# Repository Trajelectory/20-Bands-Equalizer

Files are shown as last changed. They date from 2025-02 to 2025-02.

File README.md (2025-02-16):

# Equalizer 20 Bands avec Vumètre LED


## Description du Projet
Ce projet permet de modifier le son en ajustant les niveaux de fréquence tout en affichant visuellement l'intensité du signal audio via un vumètre LED.

## Fonctionnalités
- **Égaliseur graphique 20 bandes** pour un réglage précis des fréquences audio.
- **Vumètre LED** basé sur un circuit spécialisé pour une visualisation dynamique du signal.
- **Entrée et sortie audio** pour intégration dans des systèmes hi-fi ou de studio.
- **Alimentation stabilisée** pour un fonctionnement optimal et sans bruit.
- **Conception optimisée** avec une séparation des pistes minimisant les interférences.

## Matériel Utilisé
- **Logiciel de conception** : KiCad
- **Composants principaux** :
  - Amplificateurs opérationnels (ex: TL074, TL072)
  - Filtres actifs RC pour le traitement du signal
  - Potentiomètres pour le réglage des bandes
  - Circuit de vumètre
  - LED pour l'affichage du signal
  - Connecteurs audio pour l'entrée/sortie

## Fichiers Inclus
- **Schéma KiCad** : `20 Bands Equalizer.kicad_sch`
- **PCB KiCad** : `20 Bands Equalizer.kicad_pcb`
- **Les fichiers de fabrications compatible JLCPCB`

## Améliorations Possibles
- Ajout d'un **affichage LCD** pour afficher les valeurs des bandes.
- Conception d'un **boîtier imprimé en 3D** pour l'intégration.
- Optimisation de l'alimentation pour **baisser la consommation énergétique**.

## Licence
Ce projet est sous licence **MIT**, ce qui signifie que vous pouvez l'utiliser, le modifier et le partager librement en mentionnant l'auteur original.

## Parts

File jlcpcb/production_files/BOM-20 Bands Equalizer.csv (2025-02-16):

Comment | Designator | Footprint | LCSC | Quantity
220nF | C15,C44 | C_0805_2012Metric_Pad1.18x1.45mm_HandSolder | C107131 | 2
33nF | C10,C39 | C_0805_2012Metric_Pad1.18x1.45mm_HandSolder | C107150 | 2
68nF | C36,C7 | C_0805_2012Metric_Pad1.18x1.45mm_HandSolder | C107159 | 2
1M | R11,R20,R52,R61 | R_0805_2012Metric_Pad1.20x1.40mm_HandSolder | C107700 | 4
270pF | C28,C57 | C_0805_2012Metric_Pad1.18x1.45mm_HandSolder | C113858 | 2
390R | R33,R34,R36,R37,R38,R39,R40,R41,R43,R44,R45,R46 | R_0805_2012Metric_Pad1.20x1.40mm_HandSolder | C114543 | 12
220uF | C2 | CP_Elec_10x10 | C125977 | 1
10uF | C32 | C_0805_2012Metric_Pad1.18x1.45mm_HandSolder | C1713 | 1
12nF | C25,C54 | C_0805_2012Metric_Pad1.18x1.45mm_HandSolder | C1715 | 2
150pF | C30,C43,C59,C68 | C_0805_2012Metric_Pad1.18x1.45mm_HandSolder | C1716 | 4
10K | R14,R17,R55,R58 | R_0805_2012Metric_Pad1.20x1.40mm_HandSolder | C17414 | 4
3.9nF | C20,C49 | C_0805_2012Metric_Pad1.18x1.45mm_HandSolder | C1742 | 2
47nF | C21,C50 | C_0805_2012Metric_Pad1.18x1.45mm_HandSolder | C1745 | 2
15K | R10,R51 | R_0805_2012Metric_Pad1.20x1.40mm_HandSolder | C17475 | 2
6.8nF | C27,C56 | C_0805_2012Metric_Pad1.18x1.45mm_HandSolder | C1755 | 2
220K | R13,R16,R21,R23,R25,R27,R29,R31,R47,R50,R54,R57,R6,R62,R64,R66,R68,R70,R72,R9 | R_0805_2012Metric_Pad1.20x1.40mm_HandSolder | C17556 | 20
680K | R3,R4,R5,R74,R75,R76,R77,R78 | R_0805_2012Metric_Pad1.20x1.40mm_HandSolder | C17560 | 8
8.2nF | C16,C45 | C_0805_2012Metric_Pad1.18x1.45mm_HandSolder | C1758 | 2
47K | R49,R8 | R_0805_2012Metric_Pad1.20x1.40mm_HandSolder | C17713 | 2
82K | R35,R42 | R_0805_2012Metric_Pad1.20x1.40mm_HandSolder | C17840 | 2
560pF | C26,C55 | C_0805_2012Metric_Pad1.18x1.45mm_HandSolder | C1829 | 2
390nF | C12,C41 | C_0805_2012Metric_Pad1.18x1.45mm_HandSolder | C1854267 | 2
1uF | C31,C33 | C_0805_2012Metric_Pad1.18x1.45mm_HandSolder | C215803 | 2
2N2222AU | Q1,Q2,Q4 | SOT-89-3_L4.5-W2.4-P1.50-LS4.0-BR | C21714170 | 3
100R | R19,R60 | R_0805_2012Metric_Pad1.20x1.40mm_HandSolder | C25277 | 2
1K | R12,R15,R18,R22,R24,R26,R28,R30,R32,R48,R53,R56,R59,R63,R65,R67,R69,R7,R71,R73 | R_0805_2012Metric_Pad1.20x1.40mm_HandSolder | C25623 | 20
2.2nF | C22,C51 | C_0805_2012Metric_Pad1.18x1.45mm_HandSolder | C28260 | 2
10uF | C4,C5 | C_0805_2012Metric_Pad1.18x1.45mm_HandSolder | C440198 | 2
100nF | C1,C11,C14,C17,C18,C19,C34,C37,C40,C46,C47,C48,C60,C61,C62,C63,C64,C65,C66,C67,C8 | C_0805_2012Metric_Pad1.18x1.45mm_HandSolder | C476766 | 21
LED_RED | D11,D22 | Red-ICE-CUBE-LED-5x5mm-XSCWD23MB-SunLED | C5174712 | 2
LED-GREEN | D12,D4 | Green-ICE-CUBE-LED-5x5mm-XSCWD23MB-SunLED | C5174713 | 2
LED_YELLOW | D19,D8 | Orange-ICE-CUBE-LED-5x5mm-XSCWD23MB-SunLED | C5174714 | 2
18nF | C13,C42 | C_0805_2012Metric_Pad1.18x1.45mm_HandSolder | C5186912 | 2
27nF | C23,C52 | C_0805_2012Metric_Pad1.18x1.45mm_HandSolder | C520042 | 2
2N2907AU | U1 | SOT-89-3_L4.5-W2.5-P1.50-LS4.2-TL | C5362129 | 1
1.5uF | C35,C6 | C_0805_2012Metric_Pad1.18x1.45mm_HandSolder | C6266893 | 2
820nF | C38,C9 | C_0805_2012Metric_Pad1.18x1.45mm_HandSolder | C67958 | 2
TL082 | U11 | SOIC-8_3.9x4.9mm_P1.27mm | C6966 | 1
NE5532 | U8,U9 | SOIC-8_3.9x4.9mm_P1.27mm | C7426 | 2
3.3nF | C29,C58 | C_0805_2012Metric_Pad1.18x1.45mm_HandSolder | C7467177 | 2
1N4148 | D13,D14,D16,D18,D2,D20,D3,D5,D7,D9 | D_SOD-123 | C83528 | 10
1nF | C24,C53 | C_0805_2012Metric_Pad1.18x1.45mm_HandSolder | C94121 | 2
5K |  | Potentiometer_Bourns_PTA3043_Single_Slide |  | 0
10K |  | Potentiometer_Bourns_PTA3043_Single_Slide |  | 0
LM324 |  | DIP-14_W7.62mm_LongPads |  | 0
250K |  | Potentiometer_Bourns_PTA2043_Single_Slide |  | 0
AUDIO OUT |  | Jack_3.5mm_CUI_SJ1-3523N_Horizontal |  | 0
LM324 |  | DIP-14_W7.62mm_LongPads |  | 0
5K |  | Potentiometer_Bourns_PTA3043_Single_Slide |  | 0
250K |  | Potentiometer_Bourns_PTA2043_Single_Slide |  | 0
5K |  | Potentiometer_Bourns_PTA3043_Single_Slide |  | 0
LM324 |  | DIP-14_W7.62mm_LongPads |  | 0
SPEAKER_R |  | JST_XH_S2B-XH-A-1_1x02_P2.50mm_Horizontal |  | 0
5K |  | Potentiometer_Bourns_PTA3043_Single_Slide |  | 0
10K |  | Potentiometer_Bourns_PTA3043_Single_Slide |  | 0
10K |  | Potentiometer_Bourns_PTA3043_Single_Slide |  | 0
10K |  | Potentiometer_Bourns_PTA3043_Single_Slide |  | 0
5K |  | Potentiometer_Bourns_PTA3043_Single_Slide |  | 0
5K |  | Potentiometer_Bourns_PTA3043_Single_Slide |  | 0
10K |  | Potentiometer_Bourns_PTA3043_Single_Slide |  | 0
10K |  | Potentiometer_Bourns_PTA3043_Single_Slide |  | 0
LM324 |  | DIP-14_W7.62mm_LongPads |  | 0
10K |  | Potentiometer_Bourns_PTA3043_Single_Slide |  | 0
5K |  | Potentiometer_Bourns_PTA3043_Single_Slide |  | 0
SPEAKER_L |  | JST_XH_S2B-XH-A-1_1x02_P2.50mm_Horizontal |  | 0
LM324 |  | DIP-14_W7.62mm_LongPads |  | 0
DC Jack VIN 30VDC |  | BarrelJack_GCT_DCJ200-10-A_Horizontal |  | 0
AUDIO IN |  | Jack_3.5mm_CUI_SJ1-3523N_Horizontal |  | 0
LM324 |  | DIP-14_W7.62mm_LongPads |  | 0
10K |  | Potentiometer_Bourns_PTA3043_Single_Slide |  | 0
10K |  | Potentiometer_Bourns_PTA3043_Single_Slide |  | 0
5K |  | Potentiometer_Bourns_PTA3043_Single_Slide |  | 0
10K |  | Potentiometer_Bourns_PTA3043_Single_Slide |  | 0
5K |  | Potentiometer_Bourns_PTA3043_Single_Slide |  | 0
5K |  | Potentiometer_Bourns_PTA3043_Single_Slide |  | 0

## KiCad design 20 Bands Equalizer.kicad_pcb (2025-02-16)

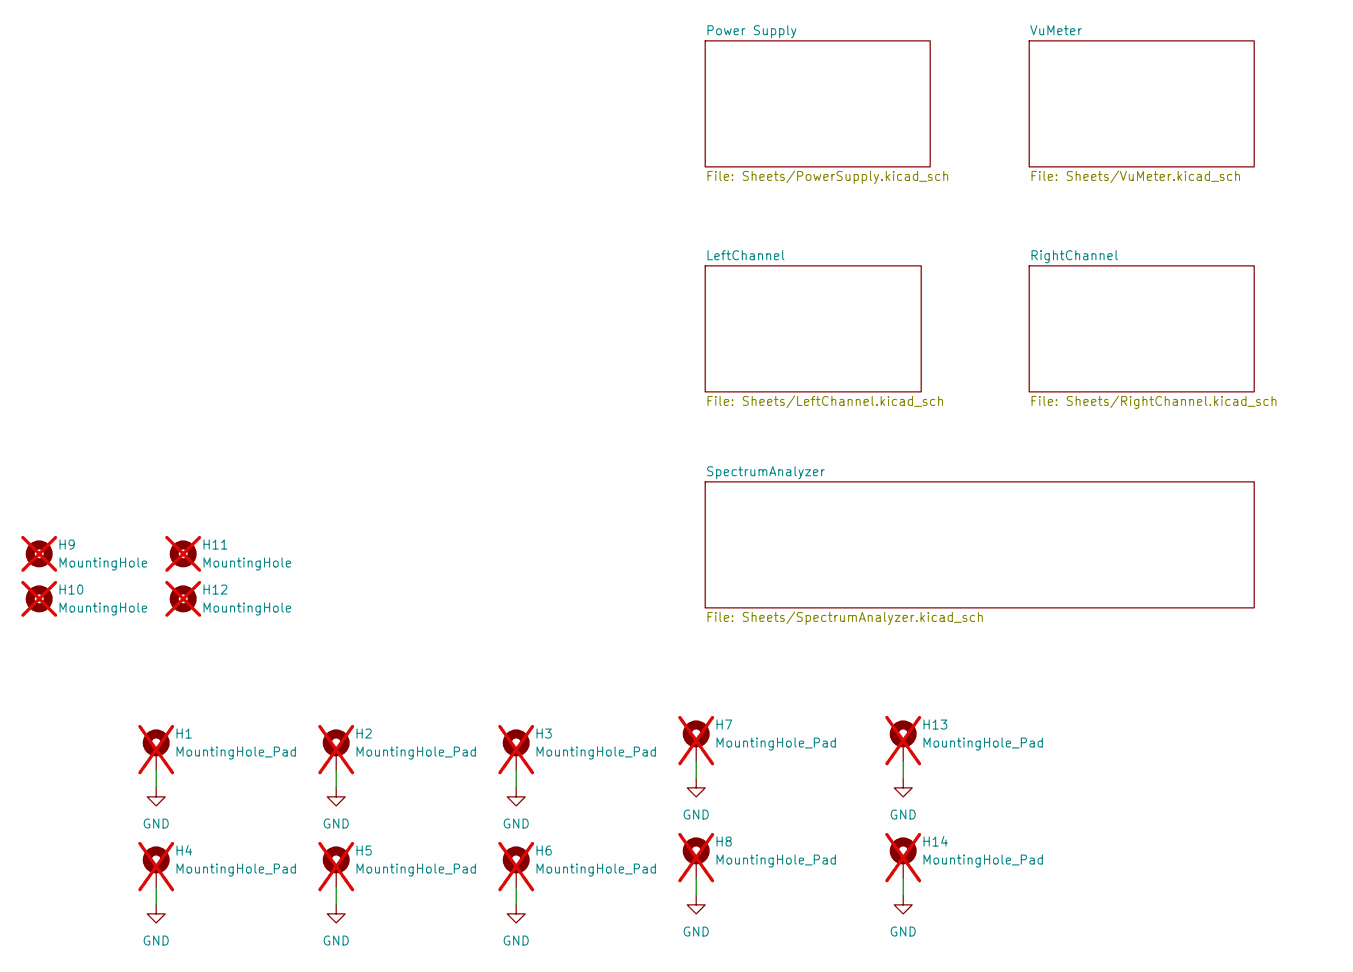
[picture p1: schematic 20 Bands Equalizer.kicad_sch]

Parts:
H1, H2, H3, H4, H5, H6, H7, H8, H13, H14: MountingHole_Pad; MountingHole_3.2mm_M3_Pad_Via; not fitted
H9, H10, H11, H12: MountingHole; MountingHole_2.5mm; not fitted

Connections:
0V: H1.1, H2.1, H3.1, H4.1, H5.1, H6.1, H7.1, H8.1, H13.1, H14.1; also elsewhere on the board

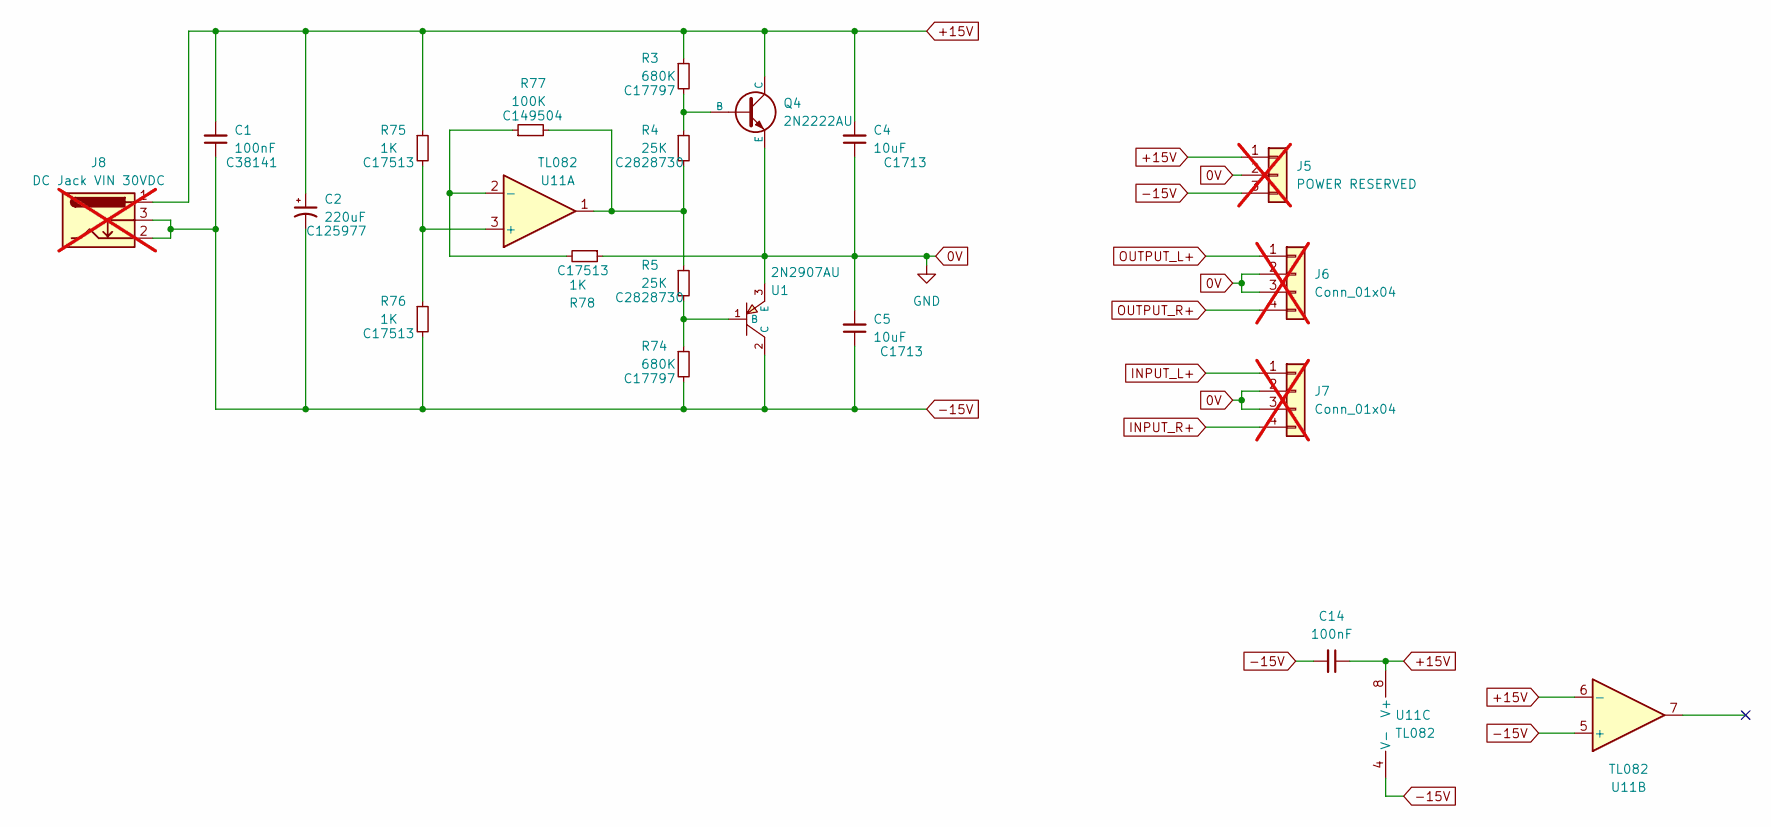
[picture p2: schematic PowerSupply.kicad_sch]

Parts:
C1, C14: 100nF; C_0805_2012Metric_Pad1.18x1.45mm_HandSolder; LCSC C38141
C2: 220uF; CP_Elec_10x10; LCSC C125977
C4, C5: 10uF; C_0805_2012Metric_Pad1.18x1.45mm_HandSolder; LCSC C1713
J5: POWER RESERVED; JST_XH_B3B-XH-A_1x03_P2.50mm_Vertical; not fitted
J6, J7: Conn_01x04; JST_XH_B4B-XH-A_1x04_P2.50mm_Vertical; not fitted
J8: DC Jack VIN 30VDC; BarrelJack_GCT_DCJ200-10-A_Horizontal; not fitted
Q4: 2N2222AU; SOT-89-3_L4.5-W2.4-P1.50-LS4.0-BR; LCSC C21714170
R3, R74: 680K; R_0805_2012Metric_Pad1.20x1.40mm_HandSolder; LCSC C17797
R4, R5: 25K; R_0805_2012Metric_Pad1.20x1.40mm_HandSolder; LCSC C2828730
R75, R76, R78: 1K; R_0805_2012Metric_Pad1.20x1.40mm_HandSolder; LCSC C17513
R77: 100K; R_0805_2012Metric_Pad1.20x1.40mm_HandSolder; LCSC C149504
U1: 2N2907AU; SOT-89-3_L4.5-W2.5-P1.50-LS4.2-TL; LCSC C5362129
U11: TL082; SOIC-8_3.9x4.9mm_P1.27mm; LCSC C6966

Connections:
0V: C4.1, C5.2, J5.2, J6.2, J6.3, J7.2, J7.3, Q4.3 (E), R78.1, U1.3 (E); also elsewhere on the board
+15V: C1.2, C2.1, C4.2, C14.1, J5.1, J8.1, Q4.2 (C), R3.1, R75.1, U11.6 (-), U11.8 (V+); also elsewhere on the board
-15V: C1.1, C2.2, C5.1, C14.2, J5.3, J8.2, J8.3, R74.2, R76.2, U1.2 (C), U11.4 (V-), U11.5 (+); also elsewhere on the board
INPUT_L+: J7.1; also elsewhere on the board
INPUT_R+: J7.4; also elsewhere on the board
unnamed: Q4.1 (B), R3.2, R4.1
unnamed: R4.2, R5.1, R77.2, U11.1
unnamed: R5.2, R74.1, U1.1 (B)
unnamed: R75.2, R76.1, U11.3 (+)
unnamed: R77.1, R78.2, U11.2 (-)
OUTPUT_L+: J6.1; also elsewhere on the board
OUTPUT_R+: J6.4; also elsewhere on the board

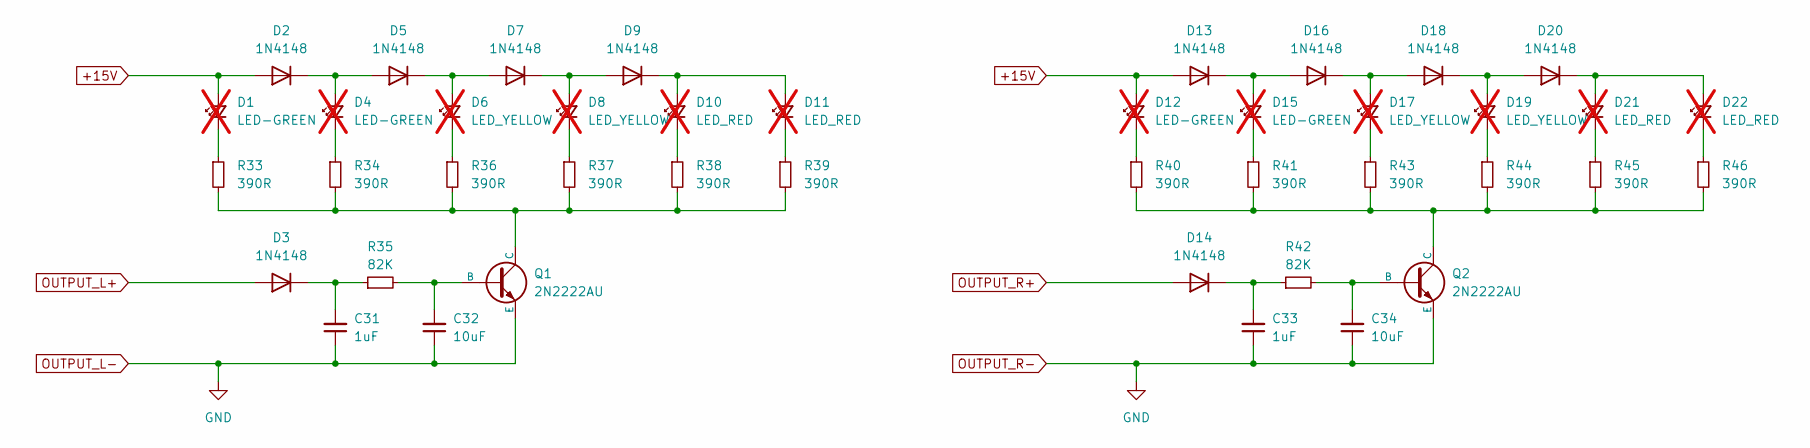
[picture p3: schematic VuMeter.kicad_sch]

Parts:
C31, C33: 1uF; C_0805_2012Metric_Pad1.18x1.45mm_HandSolder; LCSC C28323
C32, C34: 10uF; C_0805_2012Metric_Pad1.18x1.45mm_HandSolder; LCSC C1713
D1, D4, D12, D15: LED-GREEN; Green-ICE-CUBE-LED-5x5mm-XSCWD23MB-SunLED; LCSC C5174713; not fitted
D2, D3, D5, D7, D9, D13, D14, D16, D18, D20: 1N4148; D_SOD-123; LCSC C83528
D6, D8, D17, D19: LED_YELLOW; Orange-ICE-CUBE-LED-5x5mm-XSCWD23MB-SunLED; LCSC C5174714; not fitted
D10, D11, D21, D22: LED_RED; Red-ICE-CUBE-LED-5x5mm-XSCWD23MB-SunLED; LCSC C5174712; not fitted
Q1, Q2: 2N2222AU; SOT-89-3_L4.5-W2.4-P1.50-LS4.0-BR; LCSC C21714170
R33, R34, R36, R37, R38, R39, R40, R41, R43, R44, R45, R46: 390R; R_0805_2012Metric_Pad1.20x1.40mm_HandSolder; LCSC C17655
R35, R42: 82K; R_0805_2012Metric_Pad1.20x1.40mm_HandSolder; LCSC C17840

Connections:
0V: C31.1, C32.1, C33.1, C34.1, Q1.3 (E), Q2.3 (E); also elsewhere on the board
+15V: D1.2 (A), D2.2 (A), D12.2 (A), D13.2 (A); also elsewhere on the board
unnamed: D1.1 (K), R33.1
unnamed: D2.1 (K), D4.2 (A), D5.2 (A)
unnamed: C31.2, D3.1 (K), R35.1
unnamed: D4.1 (K), R34.1
unnamed: D5.1 (K), D6.2 (A), D7.2 (A)
unnamed: D6.1 (K), R36.1
unnamed: D7.1 (K), D8.2 (A), D9.2 (A)
unnamed: D8.1 (K), R37.1
unnamed: D9.1 (K), D10.2 (A), D11.2 (A)
unnamed: D10.1 (K), R38.1
unnamed: D11.1 (K), R39.1
unnamed: D12.1 (K), R40.1
unnamed: D13.1 (K), D15.2 (A), D16.2 (A)
unnamed: C33.2, D14.1 (K), R42.1
unnamed: D15.1 (K), R41.1
unnamed: D16.1 (K), D17.2 (A), D18.2 (A)
unnamed: D17.1 (K), R43.1
unnamed: D18.1 (K), D19.2 (A), D20.2 (A)
unnamed: D19.1 (K), R44.1
unnamed: D20.1 (K), D21.2 (A), D22.2 (A)
unnamed: D21.1 (K), R45.1
unnamed: D22.1 (K), R46.1
unnamed: C32.2, Q1.1 (B), R35.2
unnamed: Q1.2 (C), R33.2, R34.2, R36.2, R37.2, R38.2, R39.2
unnamed: C34.2, Q2.1 (B), R42.2
unnamed: Q2.2 (C), R40.2, R41.2, R43.2, R44.2, R45.2, R46.2
OUTPUT_L+: D3.2 (A); also elsewhere on the board
OUTPUT_R+: D14.2 (A); also elsewhere on the board

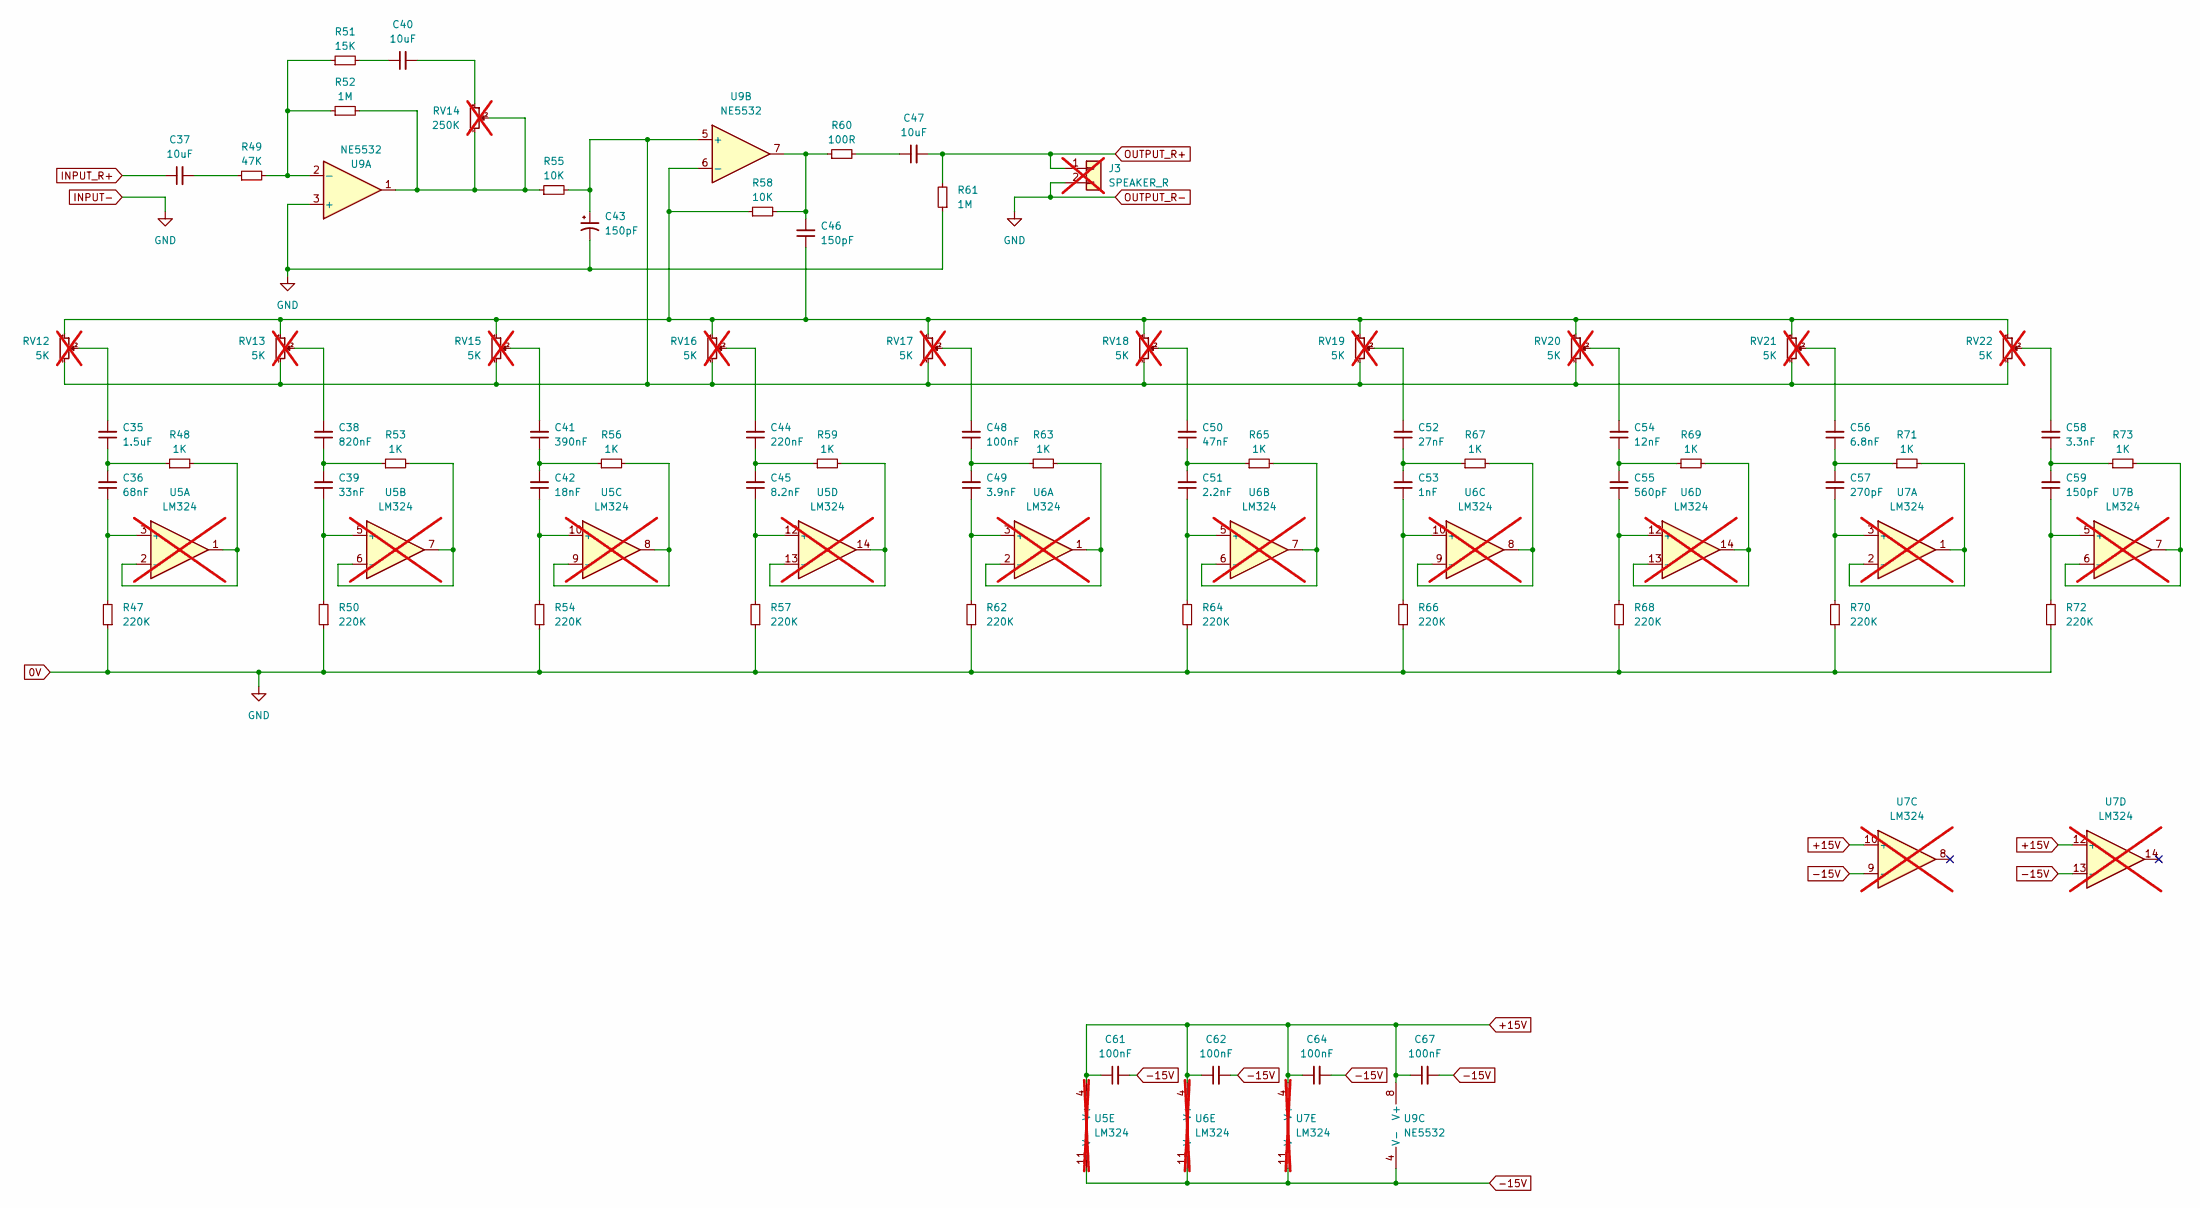
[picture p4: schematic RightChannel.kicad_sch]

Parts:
C35: 1.5uF; C_0805_2012Metric_Pad1.18x1.45mm_HandSolder; LCSC C6266893
C36: 68nF; C_0805_2012Metric_Pad1.18x1.45mm_HandSolder; LCSC C107159
C37, C40, C47: 10uF; C_0805_2012Metric_Pad1.18x1.45mm_HandSolder; LCSC C1713
C38: 820nF; C_0805_2012Metric_Pad1.18x1.45mm_HandSolder; LCSC C67958
C39: 33nF; C_0805_2012Metric_Pad1.18x1.45mm_HandSolder; LCSC C344201
C41: 390nF; C_0805_2012Metric_Pad1.18x1.45mm_HandSolder; LCSC C841545
C42: 18nF; C_0805_2012Metric_Pad1.18x1.45mm_HandSolder; LCSC C5186912
C43, C46, C59: 150pF; C_0805_2012Metric_Pad1.18x1.45mm_HandSolder; LCSC C107111
C44: 220nF; C_0805_2012Metric_Pad1.18x1.45mm_HandSolder; LCSC C6119934
C45: 8.2nF; C_0805_2012Metric_Pad1.18x1.45mm_HandSolder; LCSC C5186918
C48, C61, C62, C64, C67: 100nF; C_0805_2012Metric_Pad1.18x1.45mm_HandSolder; LCSC C38141
C49: 3.9nF; C_0805_2012Metric_Pad1.18x1.45mm_HandSolder; LCSC C97901
C50: 47nF; C_0805_2012Metric_Pad1.18x1.45mm_HandSolder; LCSC C107154
C51: 2.2nF; C_0805_2012Metric_Pad1.18x1.45mm_HandSolder; LCSC C36576
C52: 27nF; C_0805_2012Metric_Pad1.18x1.45mm_HandSolder; LCSC C520042
C53: 1nF; C_0805_2012Metric_Pad1.18x1.45mm_HandSolder; LCSC C94121
C54: 12nF; C_0805_2012Metric_Pad1.18x1.45mm_HandSolder; LCSC C38141
C55: 560pF; C_0805_2012Metric_Pad1.18x1.45mm_HandSolder; LCSC C107119
C56: 6.8nF; C_0805_2012Metric_Pad1.18x1.45mm_HandSolder; LCSC C1755
C57: 270pF; C_0805_2012Metric_Pad1.18x1.45mm_HandSolder; LCSC C113828
C58: 3.3nF; C_0805_2012Metric_Pad1.18x1.45mm_HandSolder; LCSC C7467177
J3: SPEAKER_R; JST_XH_S2B-XH-A-1_1x02_P2.50mm_Horizontal; not fitted
R47, R50, R54, R57, R62, R64, R66, R68, R70, R72: 220K; R_0805_2012Metric_Pad1.20x1.40mm_HandSolder; LCSC C17556
R48, R53, R56, R59, R63, R65, R67, R69, R71, R73: 1K; R_0805_2012Metric_Pad1.20x1.40mm_HandSolder; LCSC C17513
R49: 47K; R_0805_2012Metric_Pad1.20x1.40mm_HandSolder; LCSC C102018
R51: 15K; R_0805_2012Metric_Pad1.20x1.40mm_HandSolder; LCSC C17475
R52, R61: 1M; R_0805_2012Metric_Pad1.20x1.40mm_HandSolder; LCSC C17514
R55, R58: 10K; R_0805_2012Metric_Pad1.20x1.40mm_HandSolder; LCSC C17414
R60: 100R; R_0805_2012Metric_Pad1.20x1.40mm_HandSolder; LCSC C17408
RV12, RV13, RV15, RV16, RV17, RV18, RV19, RV20, RV21, RV22: 5K; Potentiometer_Bourns_PTA3043_Single_Slide; LCSC 652-PTA30432015CPB50; not fitted
RV14: 250K; Potentiometer_Bourns_PTA2043_Single_Slide; LCSC 652-PTA2432010CIB254; not fitted
U5, U6, U7: LM324; DIP-14_W7.62mm_LongPads; not fitted
U9: NE5532; SOIC-8_3.9x4.9mm_P1.27mm; LCSC C7426

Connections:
0V: C43.2, J3.2, R47.1, R50.1, R54.1, R57.1, R61.1, R62.1, R64.1, R66.1, R68.1, R70.1, R72.1, U9.3 (+); also elsewhere on the board
+15V: C61.1, C62.1, C64.1, C67.1, U5.4 (V+), U6.4 (V+), U7.4 (V+), U7.10 (+), U7.12 (+), U9.8 (V+); also elsewhere on the board
-15V: C61.2, C62.2, C64.2, C67.2, U5.11 (V-), U6.11 (V-), U7.9 (-), U7.11 (V-), U7.13 (-), U9.4 (V-); also elsewhere on the board
INPUT_R+: C37.1; also elsewhere on the board
unnamed: C35.1, C36.2, R48.1
unnamed: C35.2, RV12.2
unnamed: C37.2, R49.1
unnamed: C38.1, C39.2, R53.1
unnamed: C38.2, RV13.2
unnamed: C40.1, R51.2
unnamed: C40.2, RV14.1
unnamed: C41.1, C42.2, R56.1
unnamed: C41.2, RV15.2
unnamed: C44.1, C45.2, R59.1
unnamed: C44.2, RV16.2
unnamed: C46.2, R58.2, R60.1, U9.7
unnamed: C47.1, R60.2
unnamed: C48.1, C49.2, R63.1
unnamed: C48.2, RV17.2
unnamed: C50.1, C51.2, R65.1
unnamed: C50.2, RV18.2
unnamed: C52.1, C53.2, R67.1
unnamed: C52.2, RV19.2
unnamed: C54.1, C55.2, R69.1
unnamed: C54.2, RV20.2
unnamed: C56.1, C57.2, R71.1
unnamed: C56.2, RV21.2
unnamed: C58.1, C59.2, R73.1
unnamed: C58.2, RV22.2
unnamed: R52.2, R55.1, RV14.2, RV14.3, U9.1
unnamed: C36.1, R47.2, U5.3 (+)
unnamed: R48.2, U5.1, U5.2 (-)
unnamed: C39.1, R50.2, U5.5 (+)
unnamed: R53.2, U5.6 (-), U5.7
unnamed: C42.1, R54.2, U5.10 (+)
unnamed: R56.2, U5.8, U5.9 (-)
unnamed: C45.1, R57.2, U5.12 (+)
unnamed: R59.2, U5.13 (-), U5.14
unnamed: C49.1, R62.2, U6.3 (+)
unnamed: R63.2, U6.1, U6.2 (-)
unnamed: C51.1, R64.2, U6.5 (+)
unnamed: R65.2, U6.6 (-), U6.7
unnamed: C53.1, R66.2, U6.10 (+)
unnamed: R67.2, U6.8, U6.9 (-)
unnamed: C55.1, R68.2, U6.12 (+)
unnamed: R69.2, U6.13 (-), U6.14
unnamed: C57.1, R70.2, U7.3 (+)
unnamed: R71.2, U7.1, U7.2 (-)
unnamed: C59.1, R72.2, U7.5 (+)
unnamed: R73.2, U7.6 (-), U7.7
unnamed: R49.2, R51.1, R52.1, U9.2 (-)
unnamed: C43.1, R55.2, RV12.3, RV13.3, RV15.3, RV16.3, RV17.3, RV18.3, RV19.3, RV20.3, RV21.3, RV22.3, U9.5 (+)
unnamed: C46.1, R58.1, RV12.1, RV13.1, RV15.1, RV16.1, RV17.1, RV18.1, RV19.1, RV20.1, RV21.1, RV22.1, U9.6 (-)
OUTPUT_R+: C47.2, J3.1, R61.2; also elsewhere on the board

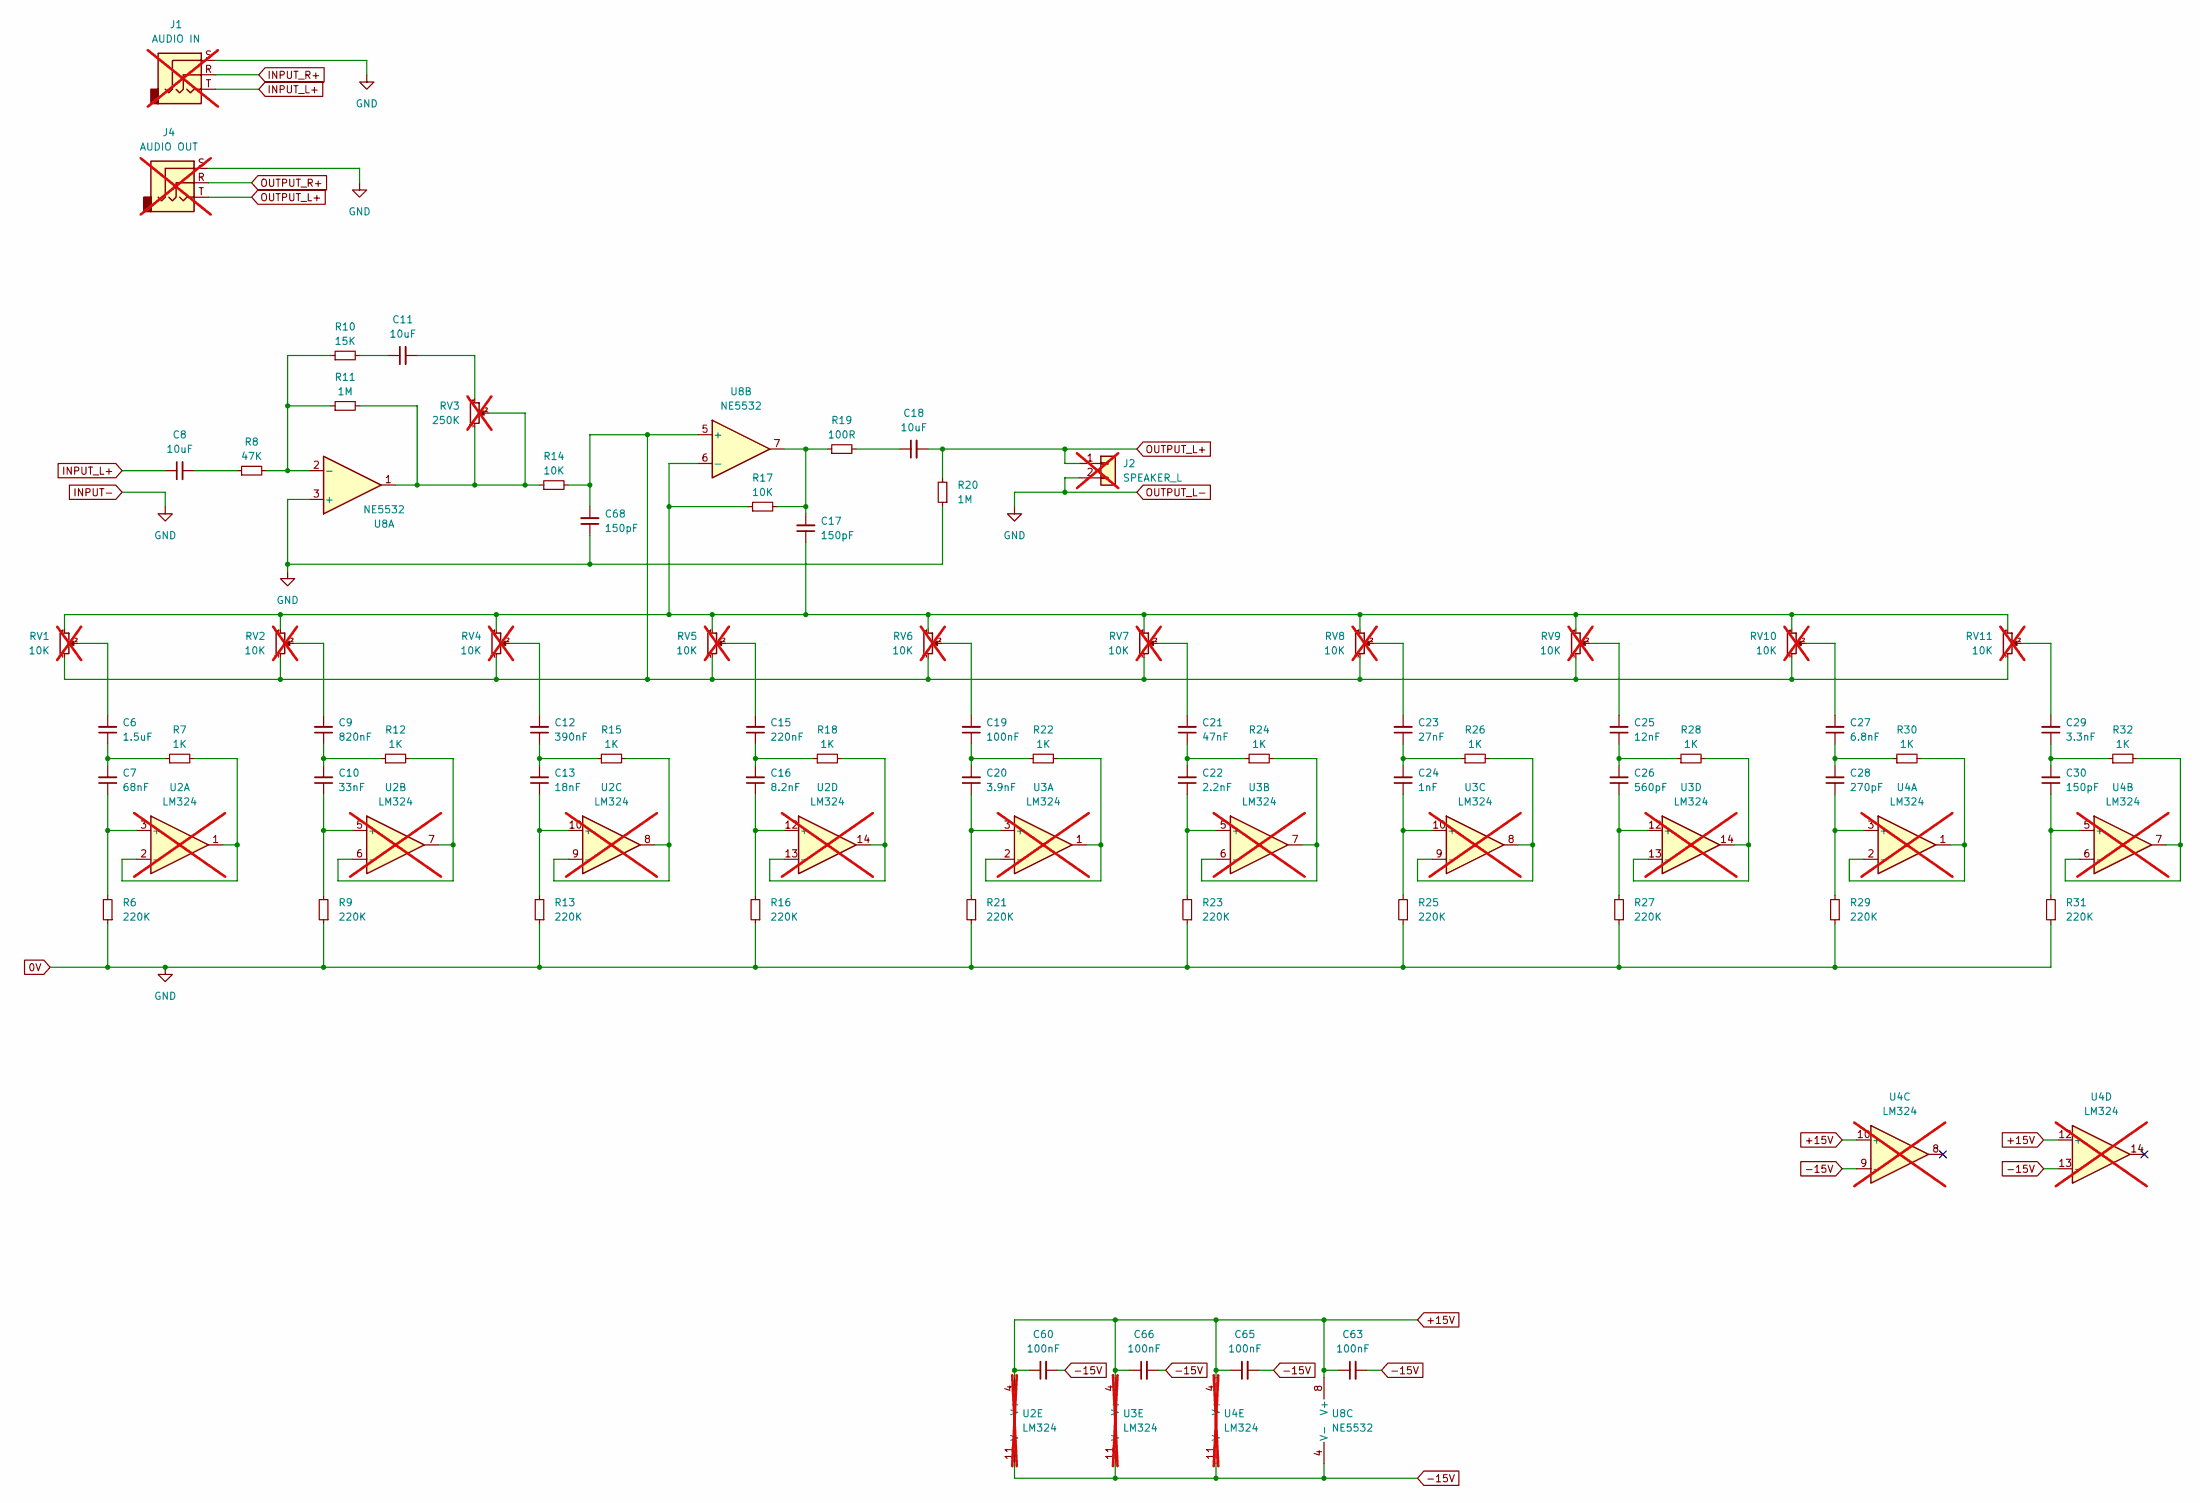
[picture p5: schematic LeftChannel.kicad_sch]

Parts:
C6: 1.5uF; C_0805_2012Metric_Pad1.18x1.45mm_HandSolder; LCSC C6266893
C7: 68nF; C_0805_2012Metric_Pad1.18x1.45mm_HandSolder; LCSC C107159
C8, C11, C18: 10uF; C_0805_2012Metric_Pad1.18x1.45mm_HandSolder; LCSC C1713
C9: 820nF; C_0805_2012Metric_Pad1.18x1.45mm_HandSolder; LCSC C67958
C10: 33nF; C_0805_2012Metric_Pad1.18x1.45mm_HandSolder; LCSC C344201
C12: 390nF; C_0805_2012Metric_Pad1.18x1.45mm_HandSolder; LCSC C841545
C13: 18nF; C_0805_2012Metric_Pad1.18x1.45mm_HandSolder; LCSC C5186912
C15: 220nF; C_0805_2012Metric_Pad1.18x1.45mm_HandSolder; LCSC C6119934
C16: 8.2nF; C_0805_2012Metric_Pad1.18x1.45mm_HandSolder; LCSC C5186918
C17, C30, C68: 150pF; C_0805_2012Metric_Pad1.18x1.45mm_HandSolder; LCSC C107111
C19, C60, C63, C65, C66: 100nF; C_0805_2012Metric_Pad1.18x1.45mm_HandSolder; LCSC C38141
C20: 3.9nF; C_0805_2012Metric_Pad1.18x1.45mm_HandSolder; LCSC C97901
C21: 47nF; C_0805_2012Metric_Pad1.18x1.45mm_HandSolder; LCSC C107154
C22: 2.2nF; C_0805_2012Metric_Pad1.18x1.45mm_HandSolder; LCSC C36576
C23: 27nF; C_0805_2012Metric_Pad1.18x1.45mm_HandSolder; LCSC C520042
C24: 1nF; C_0805_2012Metric_Pad1.18x1.45mm_HandSolder; LCSC C94121
C25: 12nF; C_0805_2012Metric_Pad1.18x1.45mm_HandSolder; LCSC C38141
C26: 560pF; C_0805_2012Metric_Pad1.18x1.45mm_HandSolder; LCSC C107119
C27: 6.8nF; C_0805_2012Metric_Pad1.18x1.45mm_HandSolder; LCSC C1755
C28: 270pF; C_0805_2012Metric_Pad1.18x1.45mm_HandSolder; LCSC C113828
C29: 3.3nF; C_0805_2012Metric_Pad1.18x1.45mm_HandSolder; LCSC C7467177
J1: AUDIO IN; Jack_3.5mm_CUI_SJ1-3523N_Horizontal; not fitted
J2: SPEAKER_L; JST_XH_S2B-XH-A-1_1x02_P2.50mm_Horizontal; not fitted
J4: AUDIO OUT; Jack_3.5mm_CUI_SJ1-3523N_Horizontal; not fitted
R6, R9, R13, R16, R21, R23, R25, R27, R29, R31: 220K; R_0805_2012Metric_Pad1.20x1.40mm_HandSolder; LCSC C17556
R7, R12, R15, R18, R22, R24, R26, R28, R30, R32: 1K; R_0805_2012Metric_Pad1.20x1.40mm_HandSolder; LCSC C17513
R8: 47K; R_0805_2012Metric_Pad1.20x1.40mm_HandSolder; LCSC C102018
R10: 15K; R_0805_2012Metric_Pad1.20x1.40mm_HandSolder; LCSC C17475
R11, R20: 1M; R_0805_2012Metric_Pad1.20x1.40mm_HandSolder; LCSC C17514
R14, R17: 10K; R_0805_2012Metric_Pad1.20x1.40mm_HandSolder; LCSC C17414
R19: 100R; R_0805_2012Metric_Pad1.20x1.40mm_HandSolder; LCSC C17408
RV1, RV2, RV4, RV5, RV6, RV7, RV8, RV9, RV10, RV11: 10K; Potentiometer_Bourns_PTA3043_Single_Slide; not fitted
RV3: 250K; Potentiometer_Bourns_PTA2043_Single_Slide; LCSC 652-PTA2432010CIB254; not fitted
U2, U3, U4: LM324; DIP-14_W7.62mm_LongPads; not fitted
U8: NE5532; SOIC-8_3.9x4.9mm_P1.27mm; LCSC C7426

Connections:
0V: C68.1, J1.S, J2.2, J4.S, R6.1, R9.1, R13.1, R16.1, R20.1, R21.1, R23.1, R25.1, R27.1, R29.1, R31.1, U8.3 (+); also elsewhere on the board
+15V: C60.1, C63.1, C65.1, C66.1, U2.4 (V+), U3.4 (V+), U4.4 (V+), U4.10 (+), U4.12 (+), U8.8 (V+); also elsewhere on the board
-15V: C60.2, C63.2, C65.2, C66.2, U2.11 (V-), U3.11 (V-), U4.9 (-), U4.11 (V-), U4.13 (-), U8.4 (V-); also elsewhere on the board
INPUT_L+: C8.1, J1.T; also elsewhere on the board
INPUT_R+: J1.R; also elsewhere on the board
unnamed: C6.1, C7.2, R7.1
unnamed: C6.2, RV1.2
unnamed: C8.2, R8.1
unnamed: C9.2, RV2.2
unnamed: C9.1, C10.2, R12.1
unnamed: C11.1, R10.2
unnamed: C11.2, RV3.1
unnamed: C12.1, C13.2, R15.1
unnamed: C12.2, RV4.2
unnamed: C15.1, C16.2, R18.1
unnamed: C15.2, RV5.2
unnamed: C17.2, R17.2, R19.1, U8.7
unnamed: C18.1, R19.2
unnamed: C19.1, C20.2, R22.1
unnamed: C19.2, RV6.2
unnamed: C21.1, C22.2, R24.1
unnamed: C21.2, RV7.2
unnamed: C23.1, C24.2, R26.1
unnamed: C23.2, RV8.2
unnamed: C25.1, C26.2, R28.1
unnamed: C25.2, RV9.2
unnamed: C27.1, C28.2, R30.1
unnamed: C27.2, RV10.2
unnamed: C29.1, C30.2, R32.1
unnamed: C29.2, RV11.2
unnamed: R11.2, R14.1, RV3.2, RV3.3, U8.1
unnamed: C7.1, R6.2, U2.3 (+)
unnamed: R7.2, U2.1, U2.2 (-)
unnamed: C10.1, R9.2, U2.5 (+)
unnamed: R12.2, U2.6 (-), U2.7
unnamed: C13.1, R13.2, U2.10 (+)
unnamed: R15.2, U2.8, U2.9 (-)
unnamed: C16.1, R16.2, U2.12 (+)
unnamed: R18.2, U2.13 (-), U2.14
unnamed: C20.1, R21.2, U3.3 (+)
unnamed: R22.2, U3.1, U3.2 (-)
unnamed: C22.1, R23.2, U3.5 (+)
unnamed: R24.2, U3.6 (-), U3.7
unnamed: C24.1, R25.2, U3.10 (+)
unnamed: R26.2, U3.8, U3.9 (-)
unnamed: C26.1, R27.2, U3.12 (+)
unnamed: R28.2, U3.13 (-), U3.14
unnamed: C28.1, R29.2, U4.3 (+)
unnamed: R30.2, U4.1, U4.2 (-)
unnamed: C30.1, R31.2, U4.5 (+)
unnamed: R32.2, U4.6 (-), U4.7
unnamed: R8.2, R10.1, R11.1, U8.2 (-)
unnamed: C68.2, R14.2, RV1.3, RV2.3, RV4.3, RV5.3, RV6.3, RV7.3, RV8.3, RV9.3, RV10.3, RV11.3, U8.5 (+)
unnamed: C17.1, R17.1, RV1.1, RV2.1, RV4.1, RV5.1, RV6.1, RV7.1, RV8.1, RV9.1, RV10.1, RV11.1, U8.6 (-)
OUTPUT_L+: C18.2, J2.1, J4.T, R20.2; also elsewhere on the board
OUTPUT_R+: J4.R; also elsewhere on the board

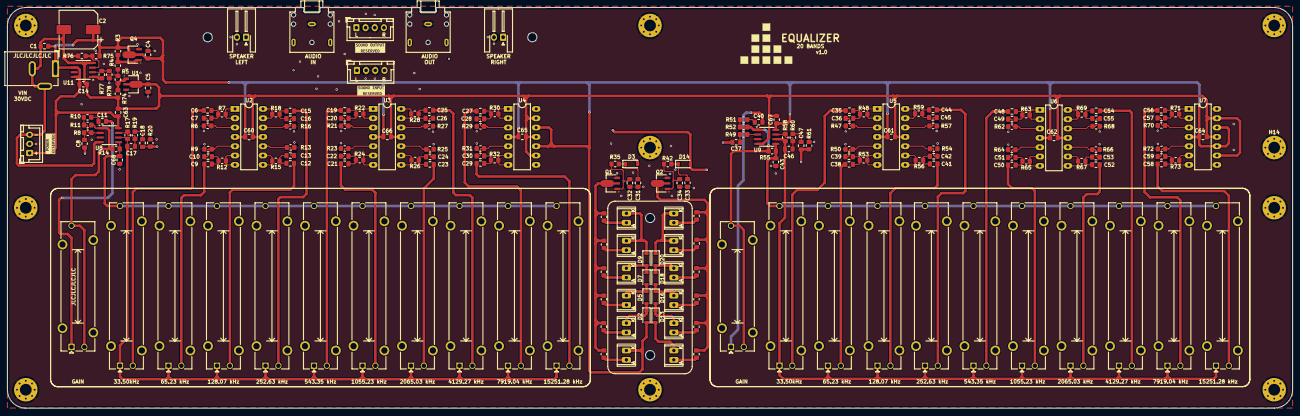
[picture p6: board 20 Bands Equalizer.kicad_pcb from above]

Board: 4 copper layers, 350.0 x 109.1 mm, 225 parts (0 on the bottom side), 136 nets.

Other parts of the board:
kibuzzard-677A2DA0: G***; kibuzzard-677A2DA0
kibuzzard-679F2E4A: G***; kibuzzard-679F2E4A
kibuzzard-679F2EA5: G***; kibuzzard-679F2EA5
